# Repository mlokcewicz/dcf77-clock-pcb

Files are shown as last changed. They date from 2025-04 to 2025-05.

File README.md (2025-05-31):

# dcf77-clock-pcb

**DCF77-controlled** radio clock PCB based on the **ATmega88** microcontroller, **MAS6181B** AM receiver, and **DS1307** RTC.

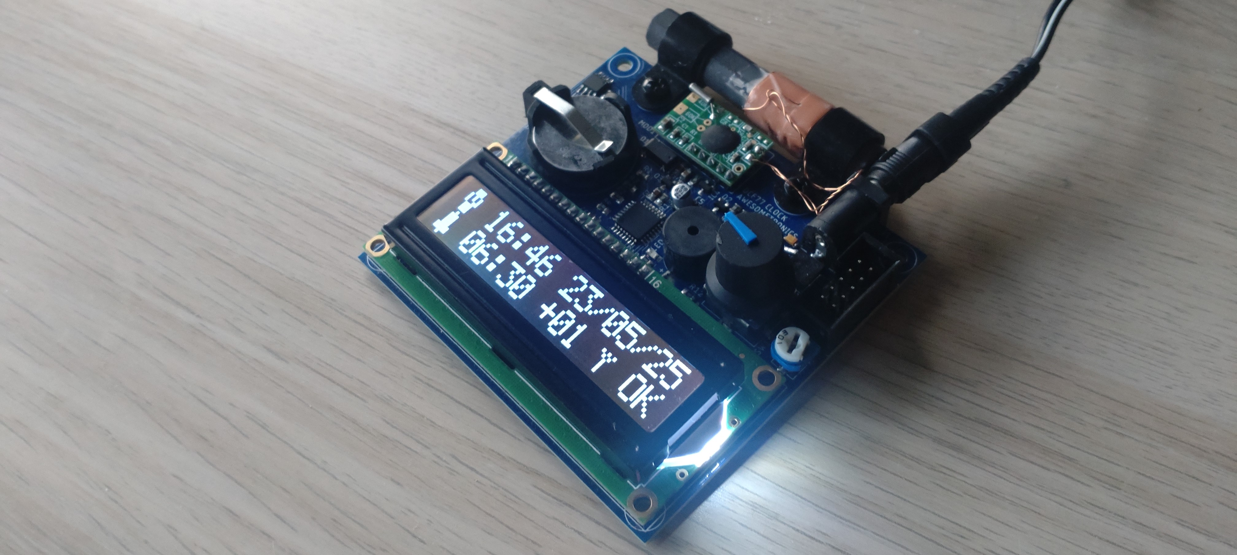
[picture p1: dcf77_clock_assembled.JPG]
dcf77_clock_assembled


**Capabilities:**
* Time and date display
* Alarm handling
* Manual date and time setting
* Automatic periodic synchronization with the DCF77 signal
* Time synchronization status display
* Time zone configuration
* DCF77 signal parameters preview during synchronization
* Time and date data available over the serial port
* Time and date retention powered by a CR2032 battery
  
**Hardware:**
* ATmega88 MCU
* MAS6181B DCF77 receiver
* DS1307 RTC + CR2032
* 2x16 HD44760 LCD
* Rotary Encoder + Button + LED + Buzzer

**Firmware:**
* C11
* Custom MCU peripheral and external circuit drivers

## Tools
* Autodesk EAGLE v9.6.2

## External links
* Firmware repository: https://github.com/mlokcewicz/dcf77-clock

## License
This project is licensed under the CERN Open Hardware Licence Version 2 - Permissive - see the [LICENSE](./LICENSE) file for details.

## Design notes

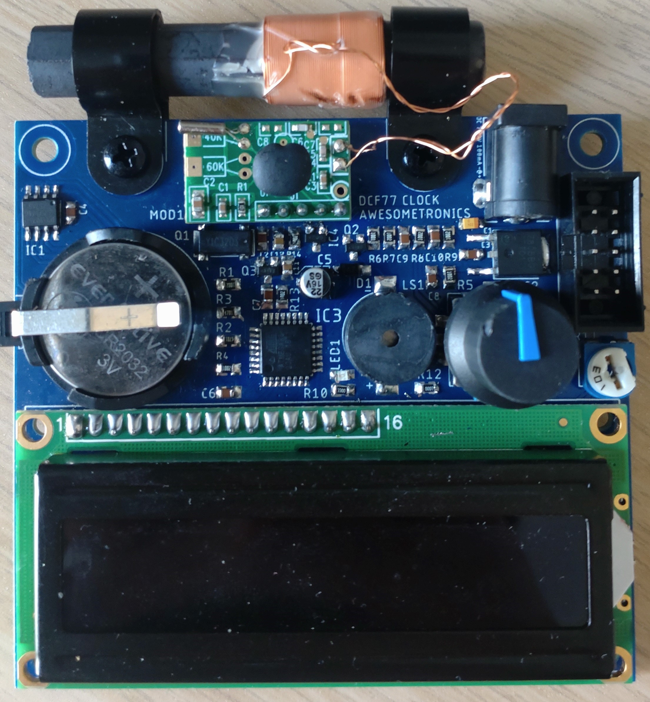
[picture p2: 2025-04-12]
dcf77_clock_final_2.JPG

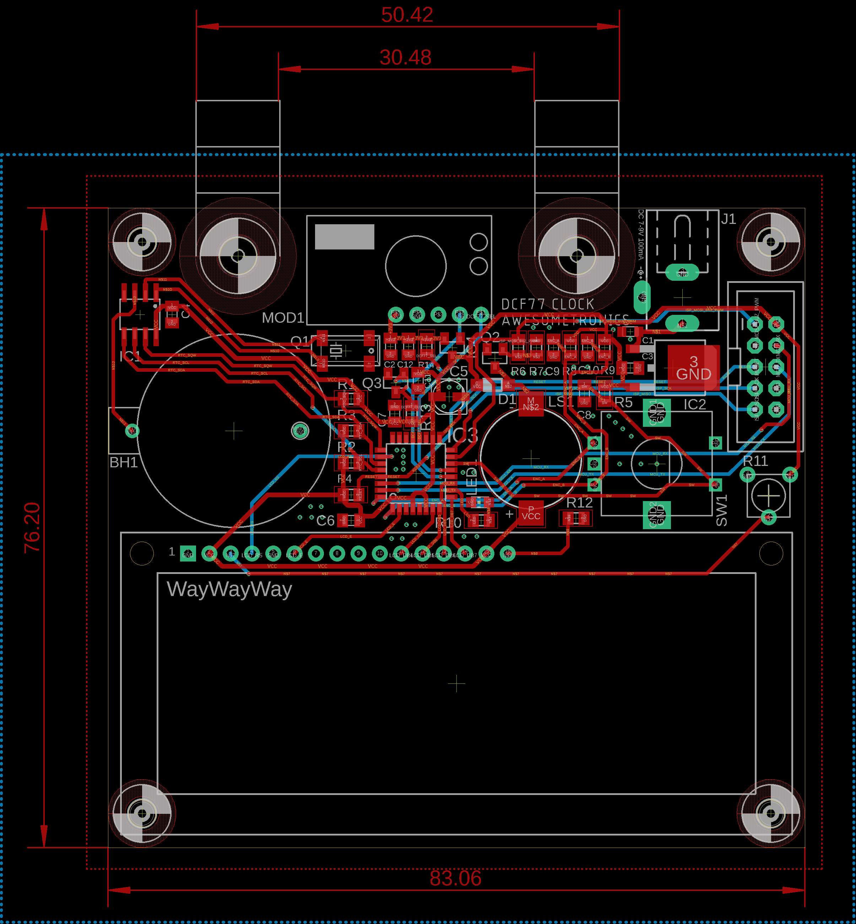
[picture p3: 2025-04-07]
dcf77_clock_pcb_image.png

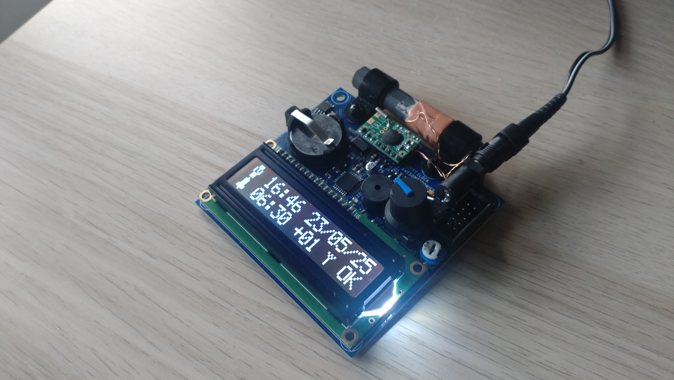
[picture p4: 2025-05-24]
dcf77_clock_final_3.JPG

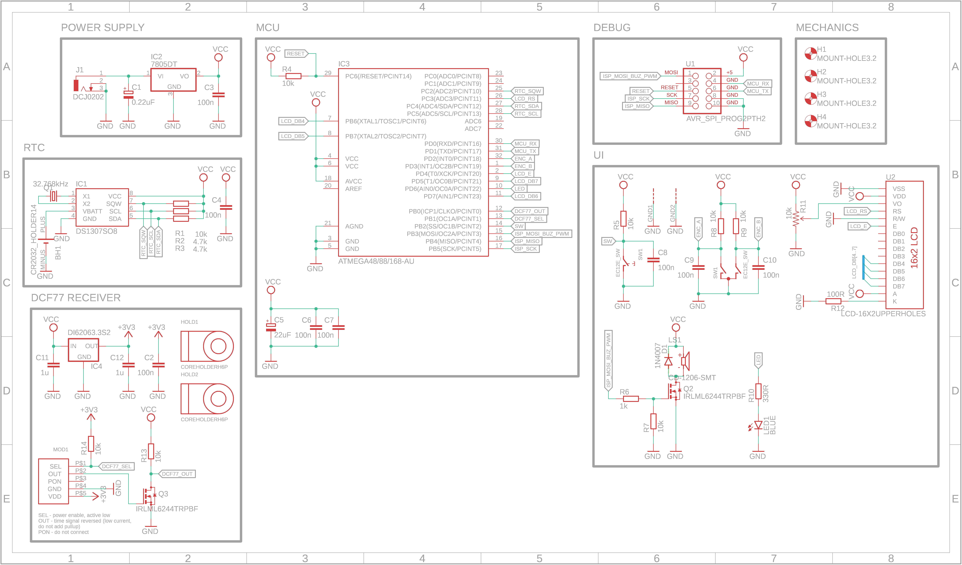
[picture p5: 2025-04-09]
dcf77_clock_sch_image.png

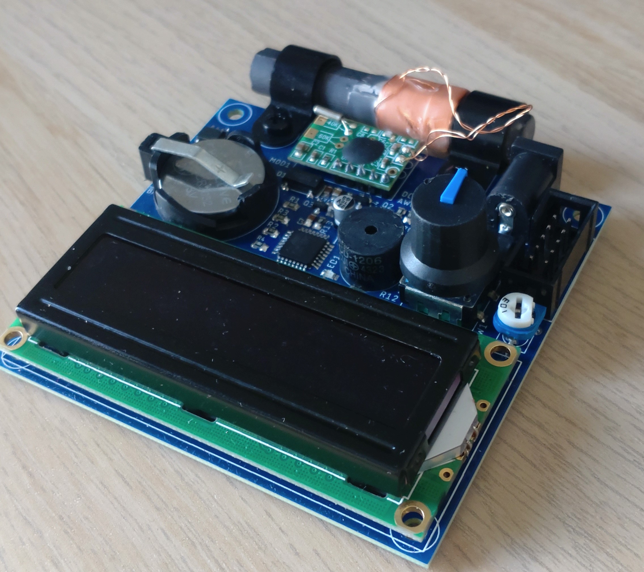
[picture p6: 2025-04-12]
dcf77_clock_final_1.JPG

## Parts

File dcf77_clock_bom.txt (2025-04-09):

Partlist exported from D:/Elektronika/Repozytoria/GitHub/hardware/dcf77-clock-pcb/dcf77_clock.sch at 09.04.2025 18:27

Qty Value              Device             Package               Parts                            Description                                  AVAILABILITY CUI_PURCHASE_URL                                                                                                                              DESCRIPTION                                                                      MF       MP             MPN          OC_FARNELL OC_NEWARK PACKAGE  POPULARITY PRICE SPICEPREFIX
1   0.22uF             CPOL-EUSMCZ        SMC_Z                 C1                               POLARIZED CAPACITOR, European symbol                                                                                                                                                                                                                                                                                                                        0                C          
1   100R               R-EU_M0805         M0805                 R12                              RESISTOR, European symbol                                                                                                                                                                                                                                                                                                                                   45               R          
8   100n               C-EUC0805K         C0805K                C2, C3, C4, C6, C7, C8, C9, C10  CAPACITOR, European symbol                                                                                                                                                                                                                                                                                                                                  52               C          
8   10k                R-EU_M0805         M0805                 R1, R4, R5, R7, R8, R9, R13, R14 RESISTOR, European symbol                                                                                                                                                                                                                                                                                                                                   45               R          
1   10k                TRIMPOTPTH         TRIM_POT_PTH          R11                                                                                                                                                                                                                                                                                                                                                                                                                      
1   1N4007             DIODE-SOD123       SOD123                D1                               DIODE                                                                                                                                                                                                                                                                                                                                                       22                          
1   1k                 R-EU_M0805         M0805                 R6                               RESISTOR, European symbol                                                                                                                                                                                                                                                                                                                                   45               R          
2   1u                 C-EUC0805K         C0805K                C11, C12                         CAPACITOR, European symbol                                                                                                                                                                                                                                                                                                                                  52               C          
1   22uF               CPOL-EUUD-4X5,8    UD-4X5,8_NICHICON     C5                               POLARIZED CAPACITOR, European symbol                                                                                                                                                                                                                                                                                                                        0                C          
1   32.768kHz          CRYSTALMM20SS      MM20SS                Q1                               CRYSTAL                                                                                                                                                                                                                                                                                                                       unknown    unknown            4                           
1   330R               R-EU_M0805         M0805                 R10                              RESISTOR, European symbol                                                                                                                                                                                                                                                                                                                                   45               R          
2   4.7k               R-EU_M0805         M0805                 R2, R3                           RESISTOR, European symbol                                                                                                                                                                                                                                                                                                                                   45               R          
1   7805DT             7805DT             TO252                 IC2                              Positive VOLTAGE REGULATOR                                                                                                                                                                                                                                                                                                                                  0                           
1   ATMEGA48/88/168-AU ATMEGA48/88/168-AU TQFP32-08             IC3                                                                                                                                                                                                                                                                                                                                                                                                                      
1   AVR_SPI_PROG2PTH2  AVR_SPI_PROG2PTH2  2X5-SHROUDED          U1                               AVR ICSP Header                                                                                                                                                                                                                                                                                                                                                                         
1   BLUE               LEDCHIP-LED0805    CHIP-LED0805          LED1                             LED                                                                                                                                                                                                                                                                                                                                                         68                          
1   CD-1206-SMT        CD-1206-SMT        CUI_CD-1206-SMT       LS1                                                                           Unavailable  https://www.cui.com/product/audio/buzzers/audio-transducers/cd-1206-smt-tr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 12 mm, 5 V, 85 dB, Surface Mount _SMT_, Sealed, Magnetic Audio Transducer Buzzer CUI Inc. CD-1206-SMT-TR                                   1206 CUI            None             
2   COREHOLDERH6P      COREHOLDERH6P      H6P                   HOLD1, HOLD2                                                                                                                                                                                                                                                                                                                                                                                                             
1   CR2032_HOLDER14    CR2032_HOLDER14    CONNFLY-DS1092-14-B6P BH1                                                                                                                                                                                                                                                                                                                                                                                                                      
1   DCF77MODULE        DCF77MODULE        DCF77MOD              MOD1                                                                                                                                                                                                                                                                                                                                                                                                                     
1   DCJ0202            DCJ0202            DCJ0202               J1                               DC POWER JACK                                                                                                                                                                                                                                                                                                                 unknown    unknown            17                          
1   DI62063.3S2        DI62063.3S2        SOT23                 IC4                                                                                                                                                                                                                                                                                                                                                                                                                      
1   DS1307SO8          DS1307SO8          SO08                  IC1                                                                                                                                                                                                                                                                                                                                                                                                                      
1   EC12E_SW           EC12E_SW           ALPS_EC12E_SW         SW1                              ALPS rotary Encoder EC12E series with switch                                                                                                                                                                                                                                                                     EC12E2424407 1520813    74M1068            3                           
2   IRLML6244TRPBF     IRLML6244TRPBF     SOT23                 Q2, Q3                           N-CHANNEL MOS FET                                                                                                                                                                                                                                                                                                                                                                       
1   LCD-16X2UPPERHOLES LCD-16X2UPPERHOLES LCD-16X2_UPPER_HOLES  U2                                                                                                                                                                                                                                                                                                                                                                                                                       
4   MOUNT-HOLE3.2      MOUNT-HOLE3.2      3,2                   H1, H2, H3, H4                   MOUNTING HOLE with drill center marker                                                                                                                                                                                                                                                                                                                      7

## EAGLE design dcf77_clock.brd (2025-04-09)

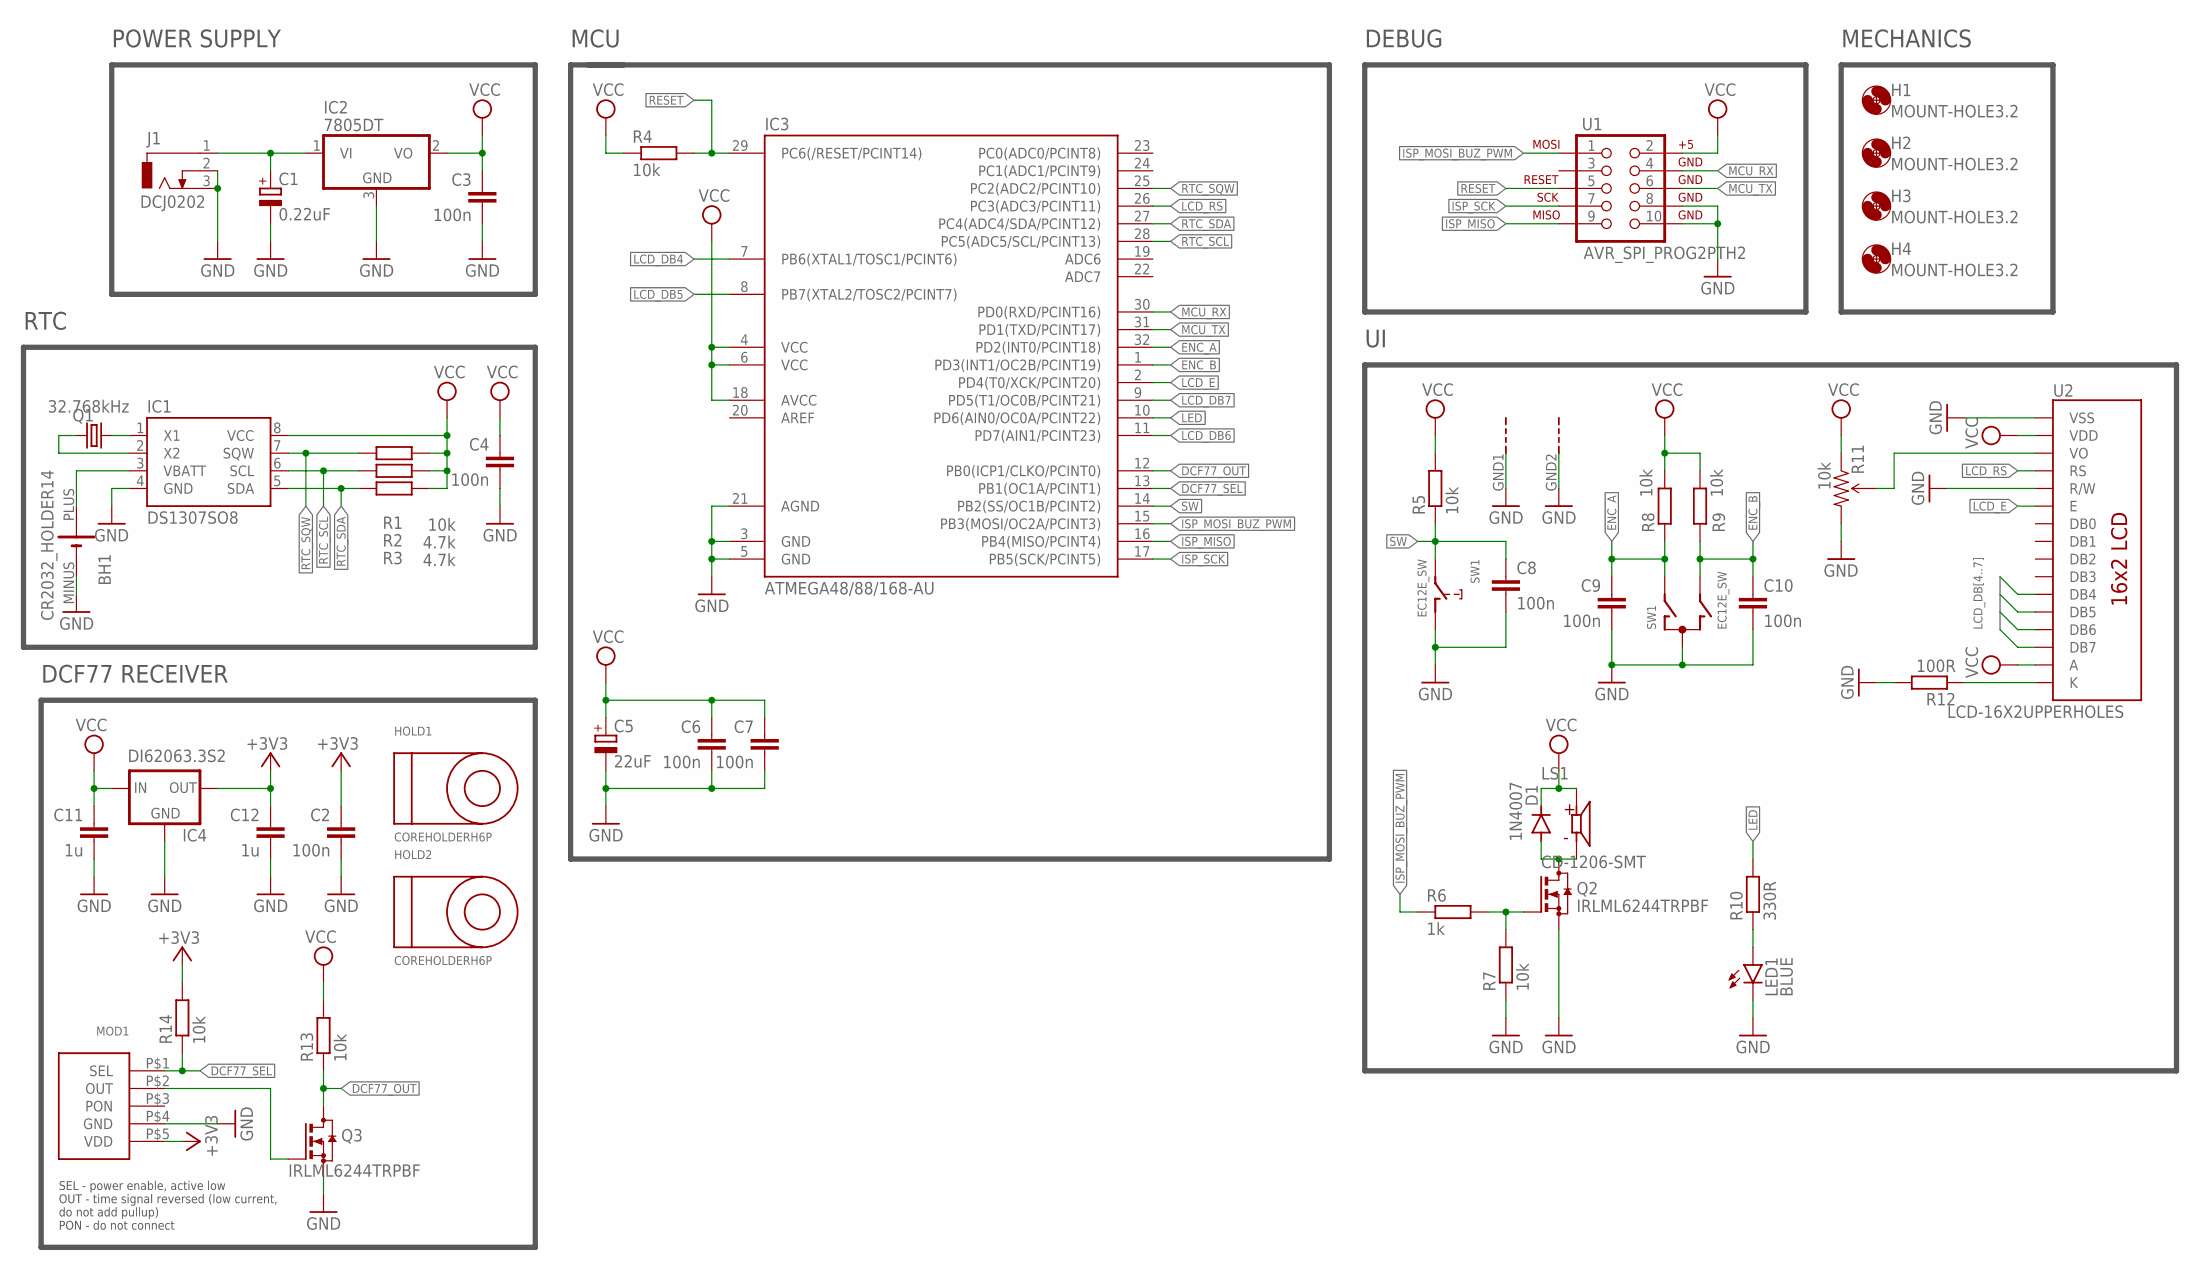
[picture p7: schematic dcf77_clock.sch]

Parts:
BH1: CR2032_HOLDER14; CONNFLY-DS1092-14-B6P
C1: 0.22uF; SMC_Z
C2, C3, C4, C6, C7, C8, C9, C10: 100n; C0805K
C5: 22uF; UD-4X5,8_NICHICON
C11, C12: 1u; C0805K
D1: 1N4007; SOD123
H1, H2, H3, H4: MOUNT-HOLE3.2; 3,2
HOLD1, HOLD2: COREHOLDERH6P; H6P
IC1: DS1307SO8; SO08
IC2: 7805DT; TO252
IC3: ATMEGA48/88/168-AU; TQFP32-08
IC4: DI62063.3S2; SOT23
J1: DCJ0202
LED1: BLUE; CHIP-LED0805
LS1: CD-1206-SMT; CUI_CD-1206-SMT
MOD1: DCF77MODULE; DCF77MOD
Q1: 32.768kHz; MM20SS
Q2, Q3: IRLML6244TRPBF; SOT23
R1, R4, R5, R7, R8, R9, R13, R14: 10k; M0805
R2, R3: 4.7k; M0805
R6: 1k; M0805
R10: 330R; M0805
R11: 10k; TRIM_POT_PTH
R12: 100R; M0805
SW1: EC12E_SW; ALPS_EC12E_SW
U1: AVR_SPI_PROG2PTH2; 2X5-SHROUDED
U2: LCD-16X2UPPERHOLES; LCD-16X2_UPPER_HOLES

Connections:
+3V3: C2.1, C12.1, IC4.2 (OUT), MOD1.P$5 (VDD), R14.2
DCF77_OUT: IC3.12 (PB0(ICP1/CLKO/PCINT0)), Q3.3 (D), R13.1
DCF77_SEL: IC3.13 (PB1(OC1A/PCINT1)), MOD1.P$1 (SEL), R14.1
ENC_A: C9.1, IC3.32 (PD2(INT0/PCINT18)), R8.1, SW1.A
ENC_B: C10.1, IC3.1 (PD3(INT1/OC2B/PCINT19)), R9.1, SW1.B
GND: BH1.MINUS, C1.-, C2.2, C3.2, C4.2, C5.-, C6.2, C7.2, C8.2, C9.2, C10.2, C11.2, C12.2, IC1.4 (GND), IC2.3 (GND), IC3.3 (GND), IC3.5 (GND), IC3.21 (AGND), IC4.1 (GND), J1.2, J1.3, LED1.C, MOD1.P$4 (GND), Q2.2 (S), Q3.2 (S), R7.1, R11.3 (CW), R12.2, SW1.C, SW1.D (1), SW1.GND1 (G), SW1.GND2 (G), U1.8, U1.10, U2.1 (VSS), U2.5 (R/W)
ISP_MISO: IC3.16 (PB4(MISO/PCINT4)), U1.9
ISP_MOSI_BUZ_PWM: IC3.15 (PB3(MOSI/OC2A/PCINT3)), R6.1, U1.1
ISP_SCK: IC3.17 (PB5(SCK/PCINT5)), U1.7
LCD_DB4: IC3.7 (PB6(XTAL1/TOSC1/PCINT6)), U2.11 (DB4)
LCD_DB5: IC3.8 (PB7(XTAL2/TOSC2/PCINT7)), U2.12 (DB5)
LCD_DB6: IC3.11 (PD7(AIN1/PCINT23)), U2.13 (DB6)
LCD_DB7: IC3.9 (PD5(T1/OC0B/PCINT21)), U2.14 (DB7)
LCD_E: IC3.2 (PD4(T0/XCK/PCINT20)), U2.6 (E)
LCD_RS: IC3.26 (PC3(ADC3/PCINT11)), U2.4 (RS)
LED: IC3.10 (PD6(AIN0/OC0A/PCINT22)), R10.2
MCU_RX: IC3.30 (PD0(RXD/PCINT16)), U1.4
MCU_TX: IC3.31 (PD1(TXD/PCINT17)), U1.6
unnamed: C1.+, IC2.1 (VI), J1.1
unnamed: D1.A, LS1.M, Q2.3 (D)
unnamed: Q2.1 (G), R6.2, R7.2
unnamed: LED1.A, R10.1
unnamed: MOD1.P$2 (OUT), Q3.1 (G)
unnamed: R11.2 (WIPER), U2.3 (VO)
unnamed: R12.1, U2.16 (K)
unnamed: IC1.1 (X1), Q1.1
unnamed: IC1.2 (X2), Q1.4 (2)
unnamed: BH1.PLUS, IC1.3 (VBATT)
RESET: IC3.29 (PC6(/RESET/PCINT14)), R4.2, U1.5
RTC_SCL: IC1.6 (SCL), IC3.28 (PC5(ADC5/SCL/PCINT13)), R2.2
RTC_SDA: IC1.5 (SDA), IC3.27 (PC4(ADC4/SDA/PCINT12)), R3.2
RTC_SQW: IC1.7 (SQW), IC3.25 (PC2(ADC2/PCINT10)), R1.2
SW: C8.1, IC3.14 (PB2(SS/OC1B/PCINT2)), R5.1, SW1.E (2)
VCC: C3.1, C4.1, C5.+, C6.1, C7.1, C11.1, D1.C, IC1.8 (VCC), IC2.2 (VO), IC3.4 (VCC), IC3.6 (VCC), IC3.18 (AVCC), IC4.3 (IN), LS1.P, R1.1, R2.1, R3.1, R4.1, R5.2, R8.2, R9.2, R11.1 (CCW), R13.2, U1.2, U2.2 (VDD), U2.15 (A)

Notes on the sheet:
POWER SUPPLY
MCU
DEBUG
MECHANICS
RTC
DCF77 RECEIVER
SEL - power enable, active low OUT - time signal reversed (low current, do not add pullup) PON - do not connect

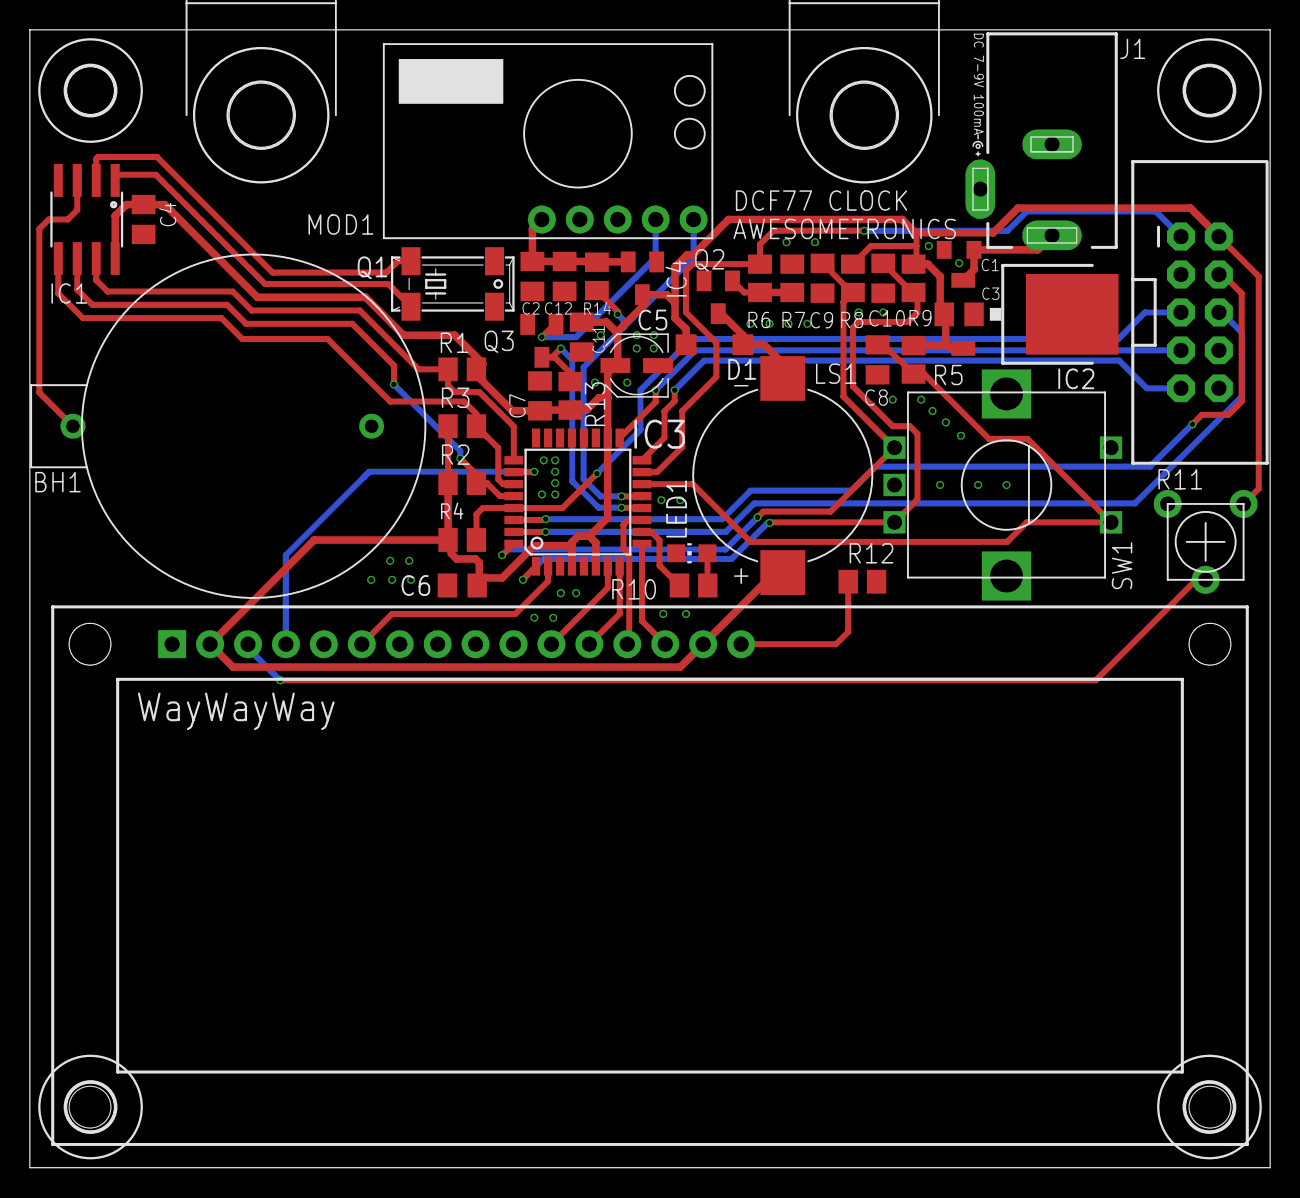
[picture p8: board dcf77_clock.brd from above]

Board: 2 copper layers, 83.1 x 76.2 mm, 48 parts (0 on the bottom side), 34 nets.

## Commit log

2025-03-18 Add THT and SMD draft
    [dcf77_clock.brd, dcf77_clock.sch]
2025-03-18 Update capacitors footprints
    [dcf77_clock.brd, dcf77_clock.sch]
2025-03-19 Add power supply and basic components schematic
    [dcf77_clock.brd, dcf77_clock.sch]
2025-03-20 Add first complete version of schematic
    [dcf77_clock.brd, dcf77_clock.sch]
2025-03-20 ERC fixes
    [dcf77_clock.brd, dcf77_clock.sch]
2025-03-21 Rearrange I2C pullups
    [dcf77_clock.brd]
2025-03-21 Add BOM
2025-03-21 Change buzzer footprint
    [dcf77_clock.brd, dcf77_clock.sch]
2025-03-22 Allign mounting holes
    [dcf77_clock.brd, dcf77_clock.sch]
2025-03-22 Replace incorrect footprints
    [dcf77_clock.brd, dcf77_clock.sch]
2025-03-22 Change oscillator footprint
    [dcf77_clock.brd, dcf77_clock.sch]
2025-03-23 Add encoder connections
    [dcf77_clock.brd]
2025-03-23 Move to parent directory
    [dcf77_clock.brd, dcf77_clock.sch]
2025-03-23 Finish signal and VCC routing
    [dcf77_clock.brd, dcf77_clock.sch]
2025-03-23 Add GND polygon and missing vias
    [dcf77_clock.brd]
2025-03-23 Place hidden encoder pins and connect to GND
    [dcf77_clock.brd, dcf77_clock.sch]
2025-03-23 DRC checked
    [dcf77_clock.brd]
2025-03-23 Add Gerber files
    [dcf77_clock.brd]
2025-03-27 Add 3V3 LDO and level shifter for MAS6181B
    [dcf77_clock.brd, dcf77_clock.sch]
2025-03-27 Maximize DC supply info
    [dcf77_clock.brd]
2025-03-27 Fit DC power supply info
    [dcf77_clock.brd]
2025-03-27 Add JLCPCB gerber files
2025-04-07 Fix CR2032 holder footprint
    [dcf77_clock.brd, dcf77_clock.sch]
2025-04-09 Change LED resistor to limit brightness
    [dcf77_clock.brd, dcf77_clock.sch]
2025-05-24 Add assembled photo

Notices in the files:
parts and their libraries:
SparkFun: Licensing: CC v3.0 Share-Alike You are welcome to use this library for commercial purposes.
